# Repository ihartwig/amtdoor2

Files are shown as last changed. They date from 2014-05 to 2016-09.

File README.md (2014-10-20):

amtdoor2
========

This repository tracks files for AMT Door 2, an RFID based lock system in use at the [Ace Monster Toys](http://acemonstertoys.org/) hackspace in Oakland, CA. A complete description of the system these files are part of, [see the description on the AMT Wiki](http://wiki.acemonstertoys.org/Door#AMT_Door_2).

Included files:
* authCode - code to run on a raspberry pi or similar auth server
* housing - 2D drawings for assembly of the door tag reader
* hwTestCode - simplified panel mcu code to test clock settings
* panelMcuCode - firmware to run on the panel mcu that interprets RFID signals and accepts opening requests from the auth server
* physical - Eagle schematic/boards for the panel mcu

## Setting up on a 16u4:

to flash a new atmega16u4 for this code using an ISP (without the bootloader):

```
$ avrdude -p atmega16u4 -P usb -c avrispmkii -u -U lfuse:w:0xfc:m -U hfuse:w:0xd0:m -U efuse:w:0xc3:m
$ make MCU=atmega16u4
$ avrdude -p atmega16u4 -P usb -c avrispmkii -U flash:w:main.hex
```

to load the bootloader first using an ISP:

```
need to set fuses. we will copy from adafruit atmega32u4 dev board.
adafruit sets to: (E:C3, H:D0, L:FC) (avrdude-- has a typo)

Extended (0 is set):
7 1 Reserved
  1 Reserved
  0 Reserved
  0 Reserved
  0 HWBE          Hardware Boot Enable
  0 BODLEVEL2(1)  Brown-out Detector trigger level
  1 BODLEVEL1(1)  Brown-out Detector trigger level
0 1 BODLEVEL0(1)  Brown-out Detector trigger level

High (0 is set):
7 1 OCDEN         Enable OCD
  1 JTAGEN        Enable JTAG
  0 SPIEN         Enable Serial Program and Data Downloading
  1 WDTON         Watchdog Timer always on
  0 EESAVE        EEPROM memory is preserved through the Chip Erase
  0 BOOTSZ1       Select Boot Size (see Table 28-7 for details)
  0 BOOTSZ0       Select Boot Size (see Table 28-7 for details)
0 0 BOOTRST       Select Bootloader Address as Reset Vector

Low (0 is set):
7 1 CKDIV8        Divide clock by 8
  1 CKOUT         Clock output
  1 SUT1          Select start-up time
  1 SUT0          Select start-up time
  1 CKSEL3        Select Clock source
  1 CKSEL2        Select Clock source
  0 CKSEL1        Select Clock source
0 0 CKSEL0        Select Clock source
```

to compile CDC bootloader (from lufa-lib trunk):
for BOOTSZ1 = BOOTSZ0 = 0. see datasheet table 27-8.

```
$ make MCU=atmega16u4 BOOT_START=0x1800 F_CPU=16000000
$ mv BootloaderCDC.hex BootloaderCDC_16u4.hex
$ avrdude -p atmega16u4 -P usb -c avrispmkii -U flash:w:BootloaderCDC_16u4.hex
```

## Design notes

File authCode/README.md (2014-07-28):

amtdoor
=======

Code that manages authenticating to and opening our door.

`check.py` is a utility to look for syntax errors in a python script.

`door_force_open.py` will force the door to open in emergencies (can only run if door_test.py is NOT running, since it talks to the arduino).

`door_test.py` listens on the usb serial port (aka an arduino) for rfids coming in. Once it reads an rfid, it compares it against a local database of valid rfids, if it matches, it sends a command to the arduino to open the door

It also listens to the arduino for the door sensor, which reports when the door opens and closes.

All of the above are also sent via http to our server for logging.

`door_test.sh` is a wrapper around door_test.py that auto-restarts on error. This is started by the doortestd at system boot.

`doortestd` is a debian system daemon script that can be used to start and stop the door test but keep it running when there are no active users on the auth computer.

`getrfids.php` updates the local database of valid rfids from the server. Gets called from cron via update-amt-rfid script.

`setup.sh` provisions the system to act as an authentication server for our door by setting up the startup and cron jobs. This can be done manually like this:
```
$ sudo cp ./doortestd /etc/init.d/doortestd
$ sudo update-rc.d door_test defaults
$ sudo cp update-amt-rfid /etc/cron.hourly/
```
Will likely need to be call as su/sudo.

The system can be unprovisioned with:
```
$ sudo update-rc.d doortestd remove
$ sudo rm /etc/init.d/door_test
$ sudo rm /etc/cron.hourly/update-amt-rfid

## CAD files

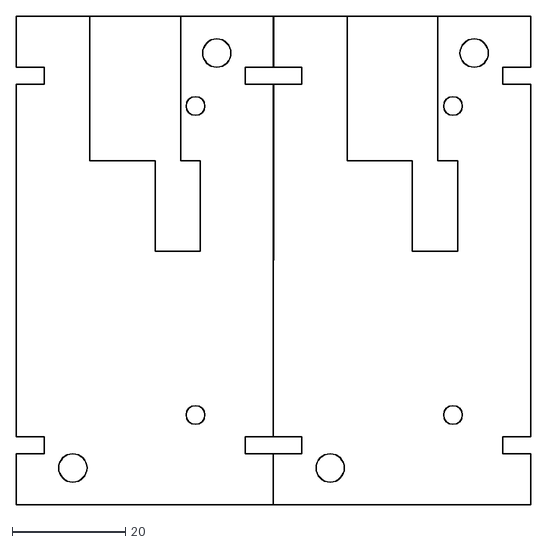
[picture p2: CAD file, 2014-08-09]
housing/amt door cut 1.dxf
90.8 x 86.2

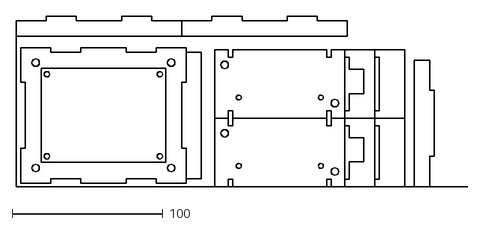
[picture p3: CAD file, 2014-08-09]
housing/amt door cut 0.dxf
300.0 x 113.0

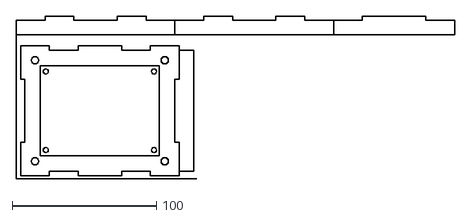
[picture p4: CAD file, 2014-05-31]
housing/amt door rfid housing.dxf
304.0 x 113.0

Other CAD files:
housing/panel_mcu_housing.dwg
housing/rfid_housing.dwg
housing/amt door cut 0.dwg
housing/amt door cut 1.dwg

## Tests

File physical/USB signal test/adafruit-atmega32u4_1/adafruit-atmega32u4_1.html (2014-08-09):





USB Test Report

Overall Results:0 of 3 Tests Failed

Test Configuration Details
Device Description
HSPacketParameter | DifferentialPP
HSSignalQuality | SMA
Use Pulse Generator | No
Test Method | USBET
Test Point | none
Test Session Details
Infiniium SW Version | 03.50.0010
Infiniium Model Number | DSO9254A
Infiniium Serial Number | MY52370102
Application SW Version | 3.81
Debug Mode Used | No
Probe (Channel 1) | Model: 10:1 1M Ohm Probe Serial: No Serial Num Atten: Calibrated (6 OCT 2012 05:12:08), Using Cal Atten (1.0070E+001) Skew: Not Calibrated, Using Default Skew
Probe (Channel 2) | Model: 10:1 1M Ohm Probe Serial: No Serial Num Atten: Not Calibrated, Using Default Atten (1.0000E+001) Skew: Not Calibrated, Using Default Skew
Probe (Channel 3) | Model: 10:1 1M Ohm Probe Serial: No Serial Num Atten: Calibrated (6 MAY 2014 16:39:34), Using Cal Atten (1.0152E+001) Skew: Not Calibrated, Using Default Skew
Last Test Date | 2014-07-28 11:12:02 UTC -07:00

## Summary of Results

Margin Thresholds
Warning | < 2 %
Critical | < 0 %

Pass | # Failed | # Trials | Test Name | Actual Value | Margin | Spec Range
 | 0 | 1 | Upstream Full Speed Signal Quality Test | Pass | 100.0 % | Pass/Fail
 | 0 | 1 | Upstream Full Speed Rise Time Test (information only) | Pass | 100.0 % | Pass/Fail
 | 0 | 1 | Upstream Full Speed Fall Time Test (information only) | Pass | 100.0 % | Pass/Fail

## Report Detail

 Upstream Full Speed Signal Quality Test Reference: USB 2.0 Specification, Section 7.1.11.,Section 7.1.2.1.

Test Summary: Pass Test Description: The full-speed data rate is nominally 12.000Mb/s. For both full-speed and low-speed signaling, the crossover voltage must be between 1.3V and 2.0V.
Test Limits:Pass/FailOverall Data Eye TestPass

Result Details:

Result Details
Port Under TestPort1Test Packet(See image)Eye Diagram(See image)LSFS Signal Eyeeye passesLSFS Signal Eye FailureN/ALSFS EOP Width TestPassLSFS EOP Width165.37 nsLSFS ReceiversN/ALSFS Signal Rate 11.9974 MHzLSFS Signal Rate TestPassLSFS Signal Rate FailureN/ALSFS Cross Over1.47 V to 1.53 VLSFS Cross Over Mean1.51 VLSFS Consecutive Jitter Range-908.312 ps to 696.659 psLSFS Consecutive RMS Jitter710.841 psLSFS Paired JK Jitter Range-148.354 ps to -32.990 psLSFS Paired JK RMS Jitter Range107.465 psLSFS Paired KJ Jitter Range-281.349 ps to 285.019 psLSFS Paired KJ RMS Jitter Range206.932 psLSFS JitterPassRisngEdge 163.02 FallingEdge 284.41

Trial 1

Trial 1: Test Packet

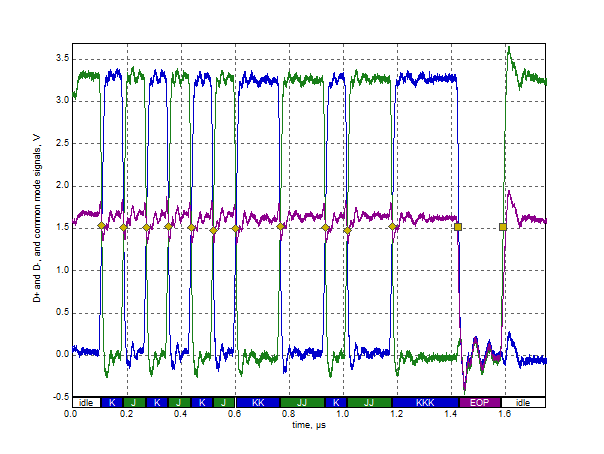
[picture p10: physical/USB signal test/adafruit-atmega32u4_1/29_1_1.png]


Trial 1: Eye Diagram

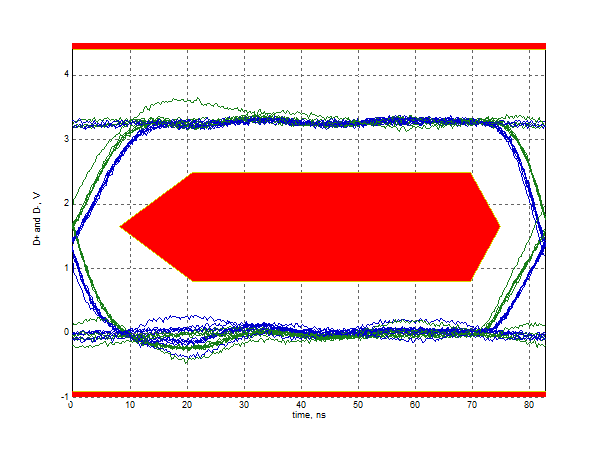
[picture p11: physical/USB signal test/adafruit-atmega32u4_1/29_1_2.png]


 Upstream Full Speed Rise Time Test (information only) Reference: USB 2.0 Specification, Section 7.1.11.,Section 7.1.2.2.

Test Summary: Pass Test Description: A USB Full Speed driver must have a single-ended rise and fall times between 4ns and 20ns. However, slew rate measurement will be made and expressed in terms of (V/us) to ensure waveform with slow corners will not result in a measured rise/fall time that is slower than the actual edge rate. The conversion from rise time to edge rate uses the specified rise time over 80% of the nominal peak to peak signal amplitude.
Test Limits:Pass/FailRise Time TestPass

Result Details:

Result Details
Test ConditionPassTest Range 4ns <= Actual Value <= 20ns Rise Time16.190 ns

 Upstream Full Speed Fall Time Test (information only) Reference: USB 2.0 Specification, Section 7.1.11.,Section 7.1.2.2.

Test Summary: Pass Test Description: A USB Full Speed driver must have a single-ended rise and fall times between 4ns and 20ns. However, slew rate measurement will be made and expressed in terms of (V/us) to ensure waveform with slow corners will not result in a measured rise/fall time that is slower than the actual edge rate. The conversion from rise time to edge rate uses the specified rise time over 80% of the nominal peak to peak signal amplitude.
Test Limits:Pass/FailFall Time TestPass

Result Details:

Result Details
Test ConditionPassTest Range 4ns <= Actual Value <= 20ns Fall Time9.280 ns

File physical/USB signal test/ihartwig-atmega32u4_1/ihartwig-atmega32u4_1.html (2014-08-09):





USB Test Report

Overall Results:0 of 3 Tests Failed

Test Configuration Details
Device Description
HSPacketParameter | DifferentialPP
HSSignalQuality | SMA
Use Pulse Generator | No
Test Method | USBET
Test Point | none
Test Session Details
Infiniium SW Version | 03.50.0010
Infiniium Model Number | DSO9254A
Infiniium Serial Number | MY52370102
Application SW Version | 3.81
Debug Mode Used | No
Probe (Channel 1) | Model: 10:1 1M Ohm Probe Serial: No Serial Num Atten: Calibrated (6 OCT 2012 05:12:08), Using Cal Atten (1.0070E+001) Skew: Not Calibrated, Using Default Skew
Probe (Channel 2) | Model: 10:1 1M Ohm Probe Serial: No Serial Num Atten: Not Calibrated, Using Default Atten (1.0000E+001) Skew: Not Calibrated, Using Default Skew
Probe (Channel 3) | Model: 10:1 1M Ohm Probe Serial: No Serial Num Atten: Calibrated (6 MAY 2014 16:39:34), Using Cal Atten (1.0152E+001) Skew: Not Calibrated, Using Default Skew
Last Test Date | 2014-07-28 11:35:18 UTC -07:00

## Summary of Results

Margin Thresholds
Warning | < 2 %
Critical | < 0 %

Pass | # Failed | # Trials | Test Name | Actual Value | Margin | Spec Range
 | 0 | 1 | Upstream Full Speed Signal Quality Test | Pass | 100.0 % | Pass/Fail
 | 0 | 1 | Upstream Full Speed Rise Time Test (information only) | Pass | 100.0 % | Pass/Fail
 | 0 | 1 | Upstream Full Speed Fall Time Test (information only) | Pass | 100.0 % | Pass/Fail

## Report Detail

 Upstream Full Speed Signal Quality Test Reference: USB 2.0 Specification, Section 7.1.11.,Section 7.1.2.1.

Test Summary: Pass Test Description: The full-speed data rate is nominally 12.000Mb/s. For both full-speed and low-speed signaling, the crossover voltage must be between 1.3V and 2.0V.
Test Limits:Pass/FailOverall Data Eye TestPass

Result Details:

Result Details
Port Under TestPort1Test Packet(See image)Eye Diagram(See image)LSFS Signal Eyeeye passesLSFS Signal Eye FailureN/ALSFS EOP Width TestPassLSFS EOP Width165.57 nsLSFS ReceiversN/ALSFS Signal Rate 11.9984 MHzLSFS Signal Rate TestPassLSFS Signal Rate FailureN/ALSFS Cross Over1.55 V to 1.62 VLSFS Cross Over Mean1.58 VLSFS Consecutive Jitter Range-848.672 ps to 686.408 psLSFS Consecutive RMS Jitter616.931 psLSFS Paired JK Jitter Range-136.159 ps to -132.254 psLSFS Paired JK RMS Jitter Range134.221 psLSFS Paired KJ Jitter Range-292.809 ps to 198.516 psLSFS Paired KJ RMS Jitter Range179.996 psLSFS JitterPassRisngEdge 178.33 FallingEdge 314.11

Trial 1

Trial 1: Test Packet

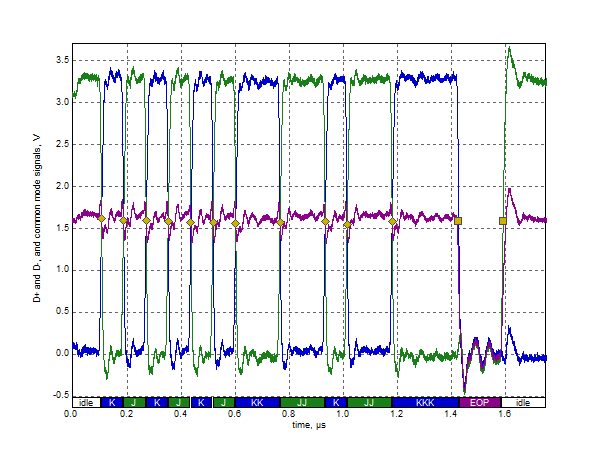
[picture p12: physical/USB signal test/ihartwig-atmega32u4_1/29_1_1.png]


Trial 1: Eye Diagram

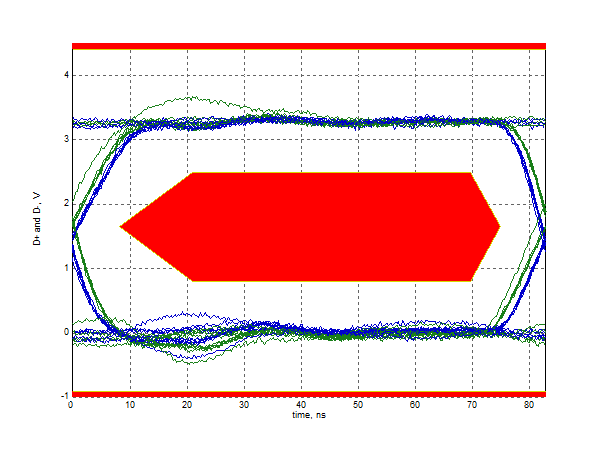
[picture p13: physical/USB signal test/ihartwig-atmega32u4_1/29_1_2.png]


 Upstream Full Speed Rise Time Test (information only) Reference: USB 2.0 Specification, Section 7.1.11.,Section 7.1.2.2.

Test Summary: Pass Test Description: A USB Full Speed driver must have a single-ended rise and fall times between 4ns and 20ns. However, slew rate measurement will be made and expressed in terms of (V/us) to ensure waveform with slow corners will not result in a measured rise/fall time that is slower than the actual edge rate. The conversion from rise time to edge rate uses the specified rise time over 80% of the nominal peak to peak signal amplitude.
Test Limits:Pass/FailRise Time TestPass

Result Details:

Result Details
Test ConditionPassTest Range 4ns <= Actual Value <= 20ns Rise Time14.800 ns

 Upstream Full Speed Fall Time Test (information only) Reference: USB 2.0 Specification, Section 7.1.11.,Section 7.1.2.2.

Test Summary: Pass Test Description: A USB Full Speed driver must have a single-ended rise and fall times between 4ns and 20ns. However, slew rate measurement will be made and expressed in terms of (V/us) to ensure waveform with slow corners will not result in a measured rise/fall time that is slower than the actual edge rate. The conversion from rise time to edge rate uses the specified rise time over 80% of the nominal peak to peak signal amplitude.
Test Limits:Pass/FailFall Time TestPass

Result Details:

Result Details
Test ConditionPassTest Range 4ns <= Actual Value <= 20ns Fall Time8.400 ns

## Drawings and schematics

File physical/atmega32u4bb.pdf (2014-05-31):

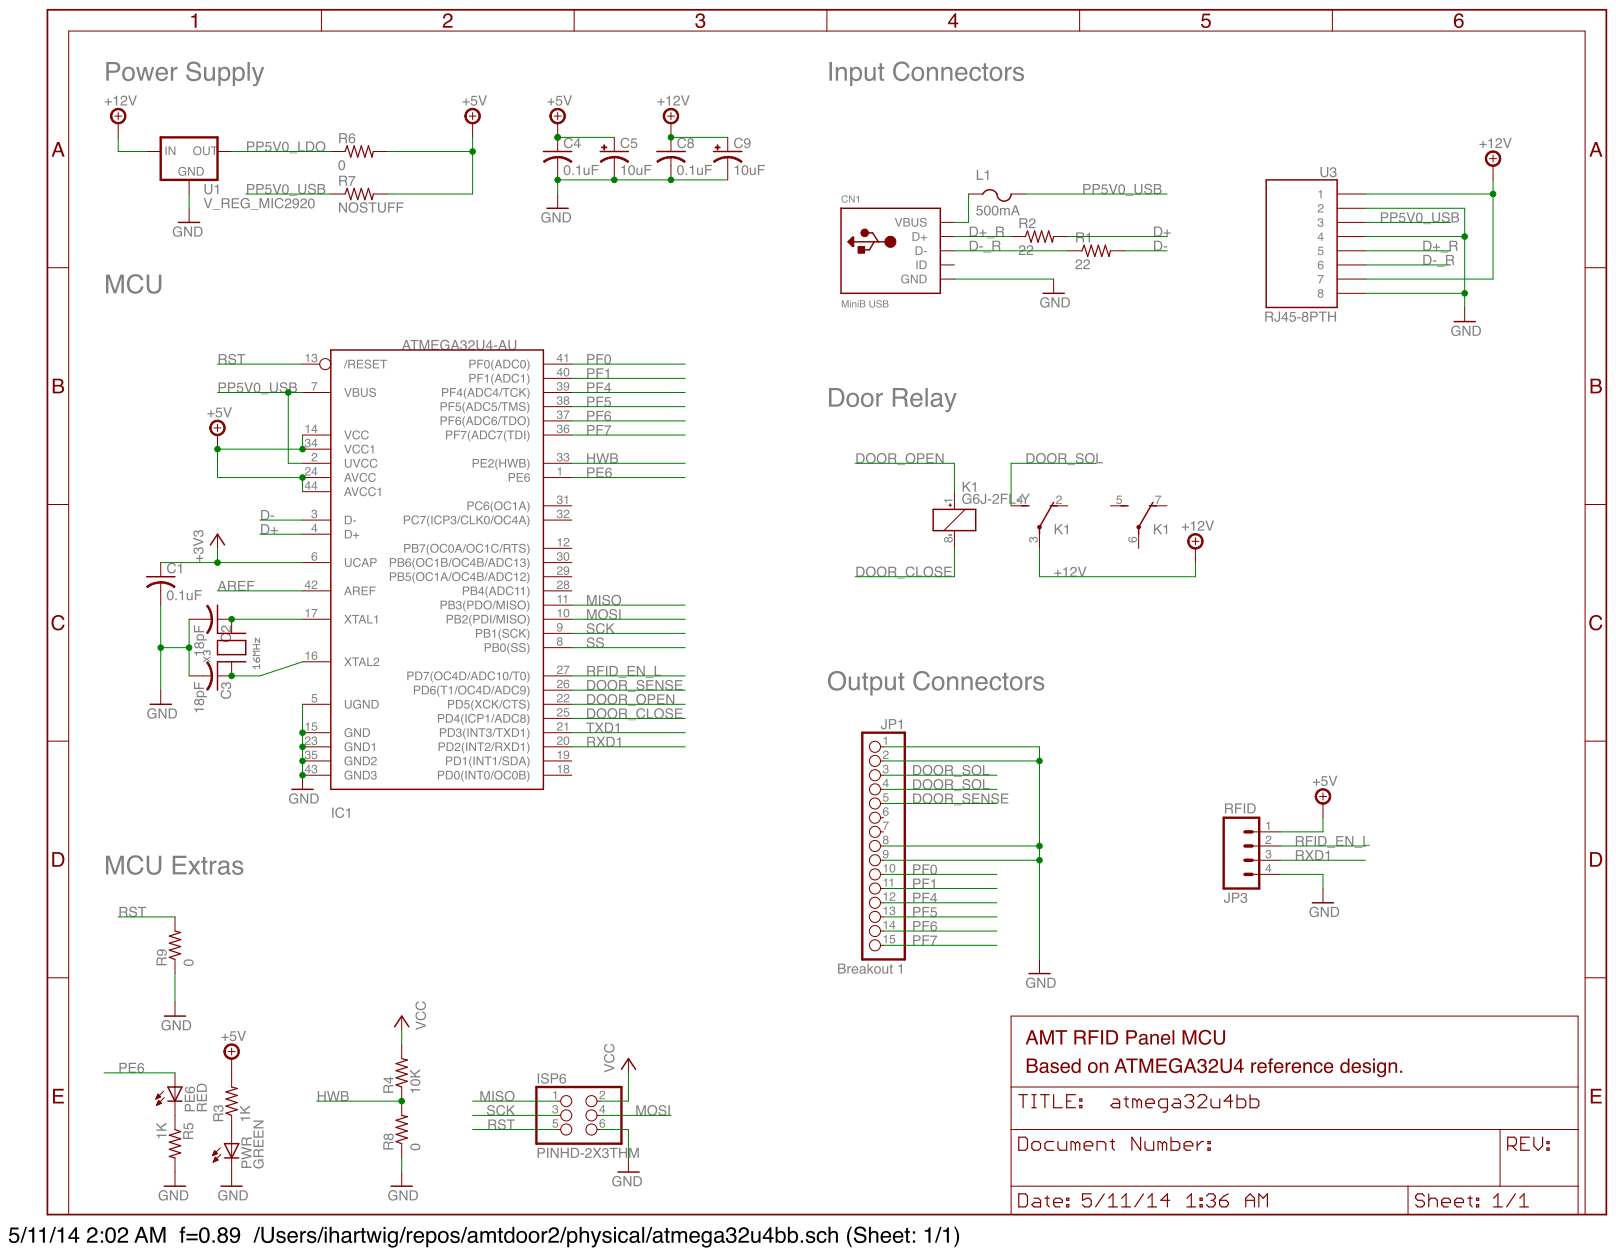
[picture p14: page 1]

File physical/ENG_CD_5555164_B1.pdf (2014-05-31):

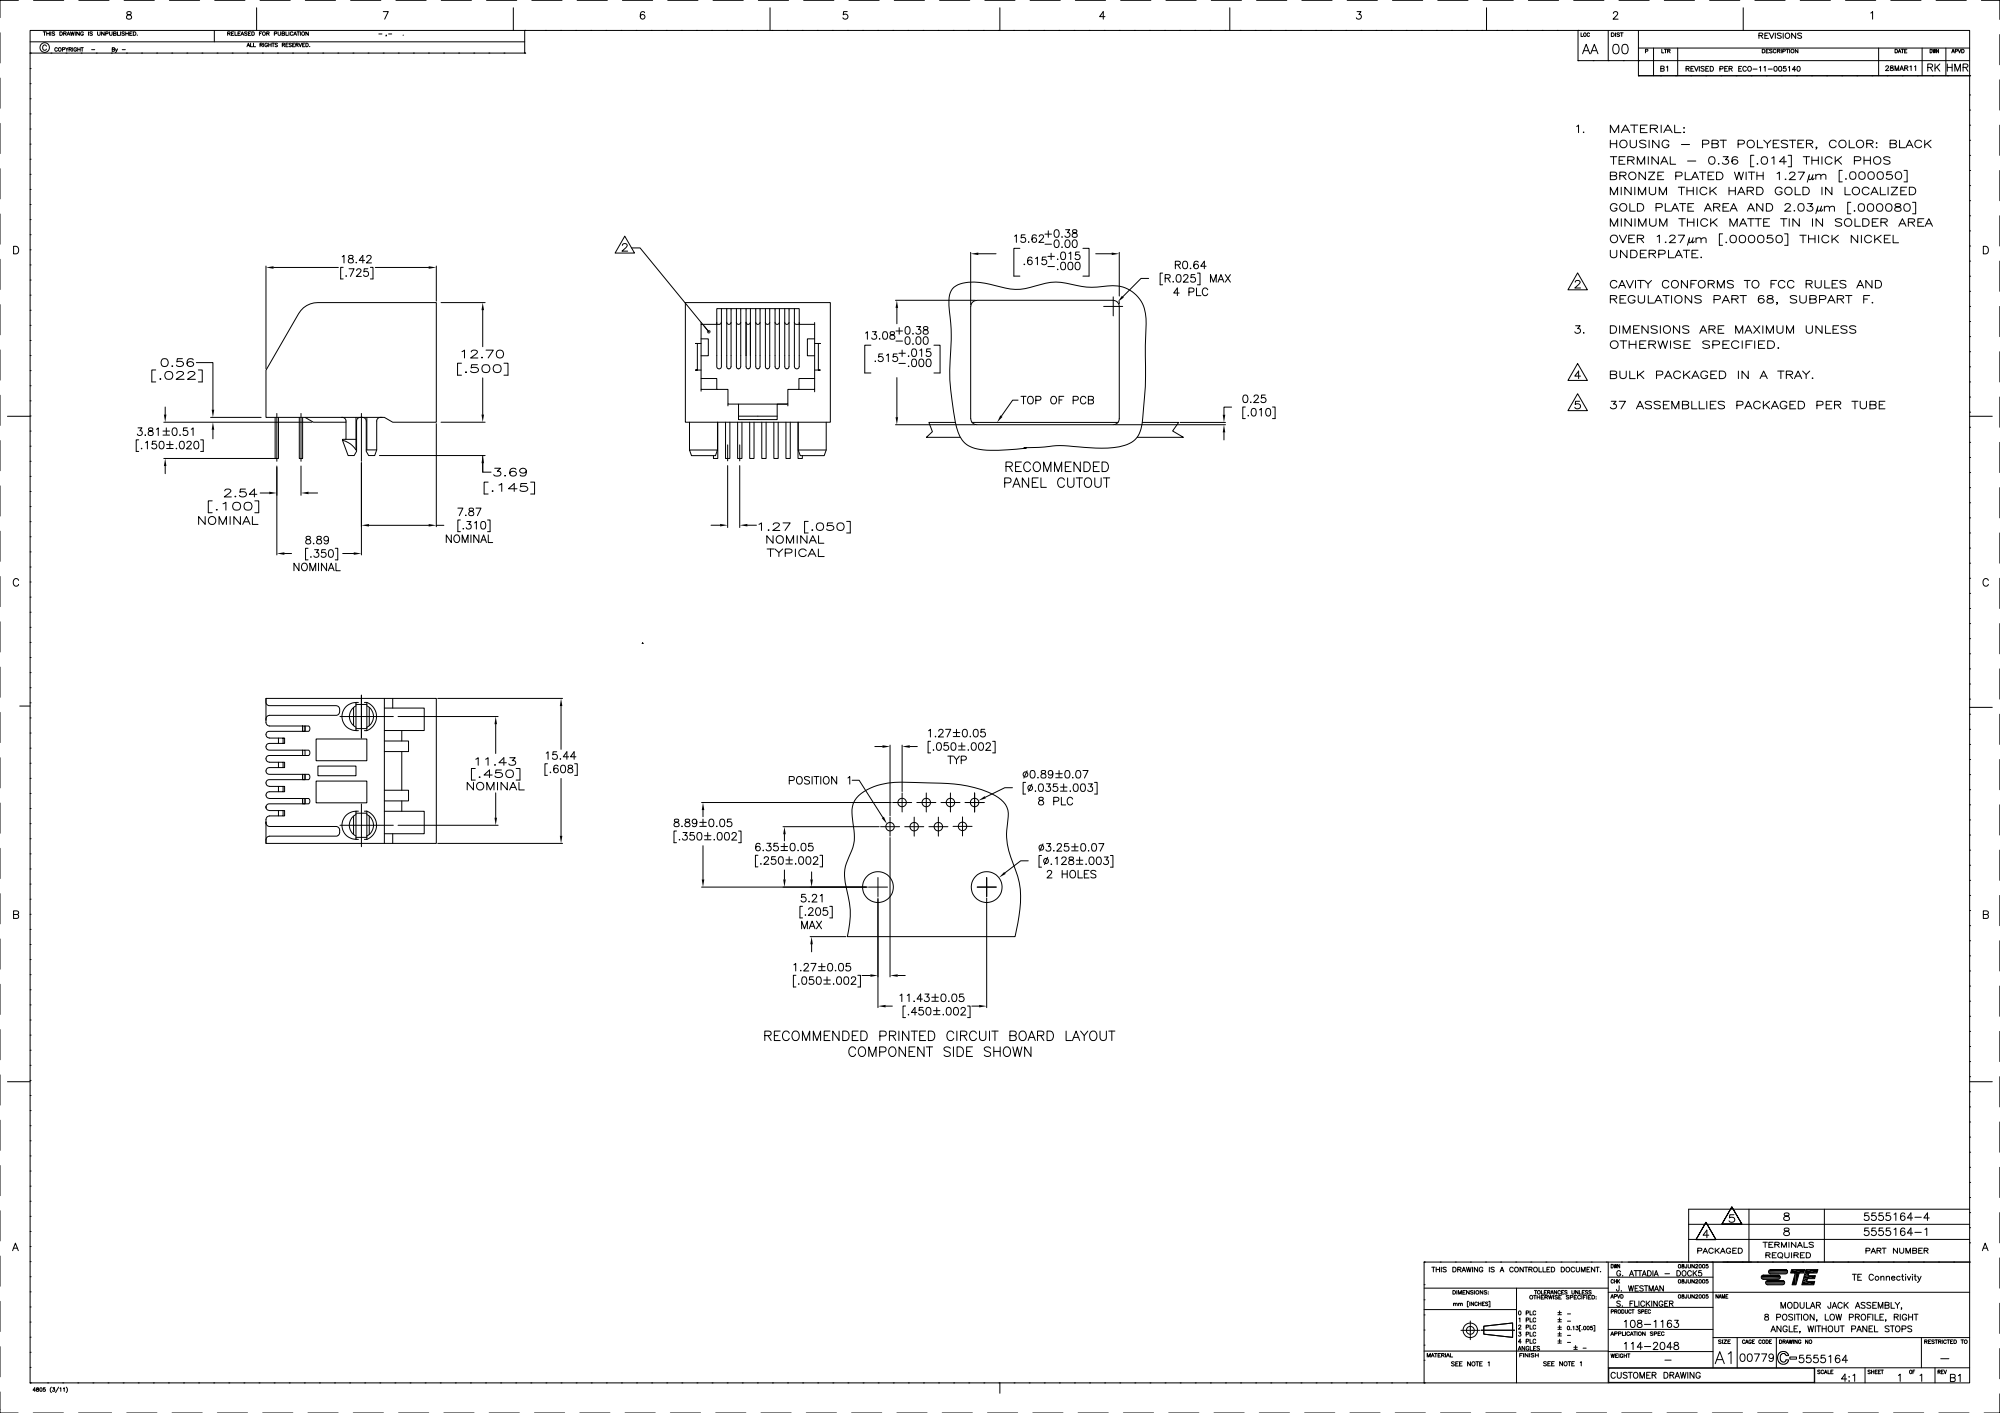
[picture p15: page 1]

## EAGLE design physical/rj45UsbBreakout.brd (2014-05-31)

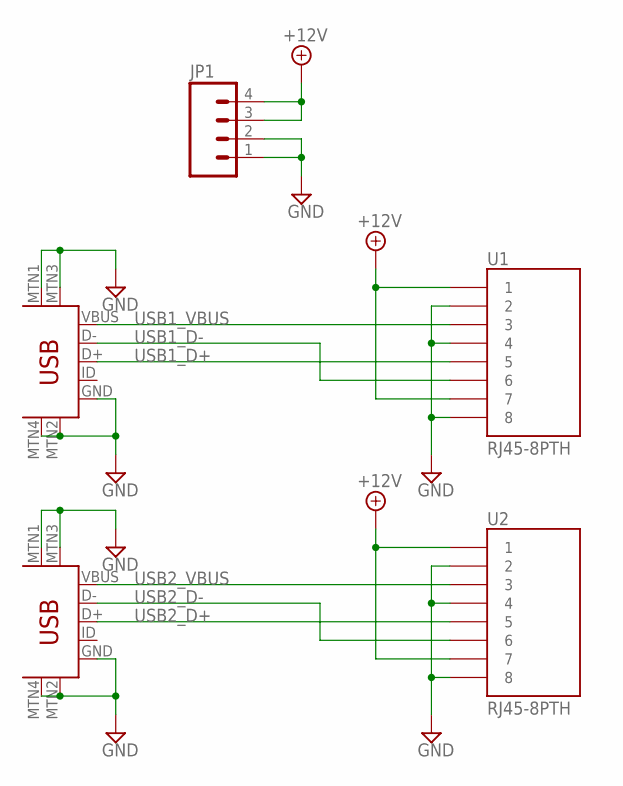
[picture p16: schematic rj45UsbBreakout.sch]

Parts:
JP1: M04LOCK; 1X04_LOCK
U1, U2: RJ45-8PTH; RJ45-8
U3, U4: USB-MINIB-5PIN; USB-MINIB

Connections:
+12V: JP1.3, JP1.4, U1.1, U1.7, U2.1, U2.7
GND: JP1.1, JP1.2, U1.2, U1.4, U1.8, U2.2, U2.4, U2.8, U3.GND, U3.MTN1 (MTN2), U3.MTN2 (MTN3), U3.MTN3 (MTN1), U3.MTN4, U4.GND, U4.MTN1 (MTN2), U4.MTN2 (MTN3), U4.MTN3 (MTN1), U4.MTN4
USB1_D+: U1.5, U3.D+
USB1_D-: U1.6, U3.D-
USB1_VBUS: U1.3, U3.VBUS
USB2_D+: U2.5, U4.D+
USB2_D-: U2.6, U4.D-
USB2_VBUS: U2.3, U4.VBUS

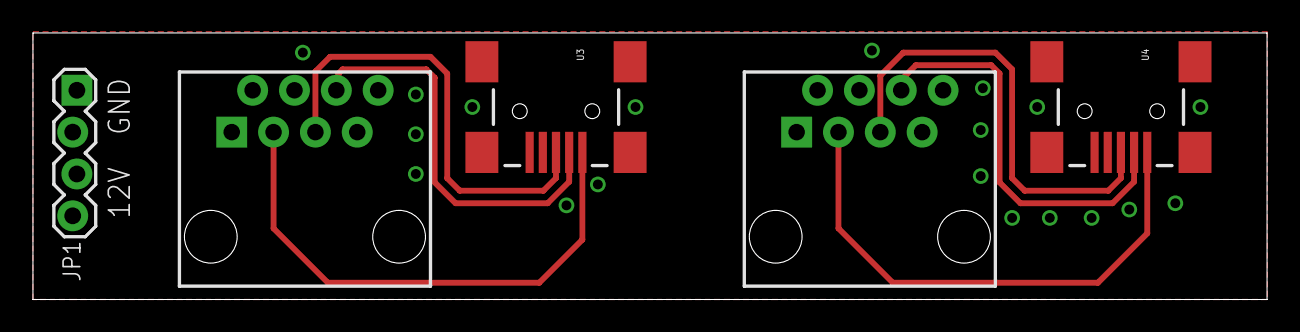
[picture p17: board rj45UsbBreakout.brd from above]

Board: 2 copper layers, 74.9 x 16.2 mm, 5 parts (0 on the bottom side), 8 nets.

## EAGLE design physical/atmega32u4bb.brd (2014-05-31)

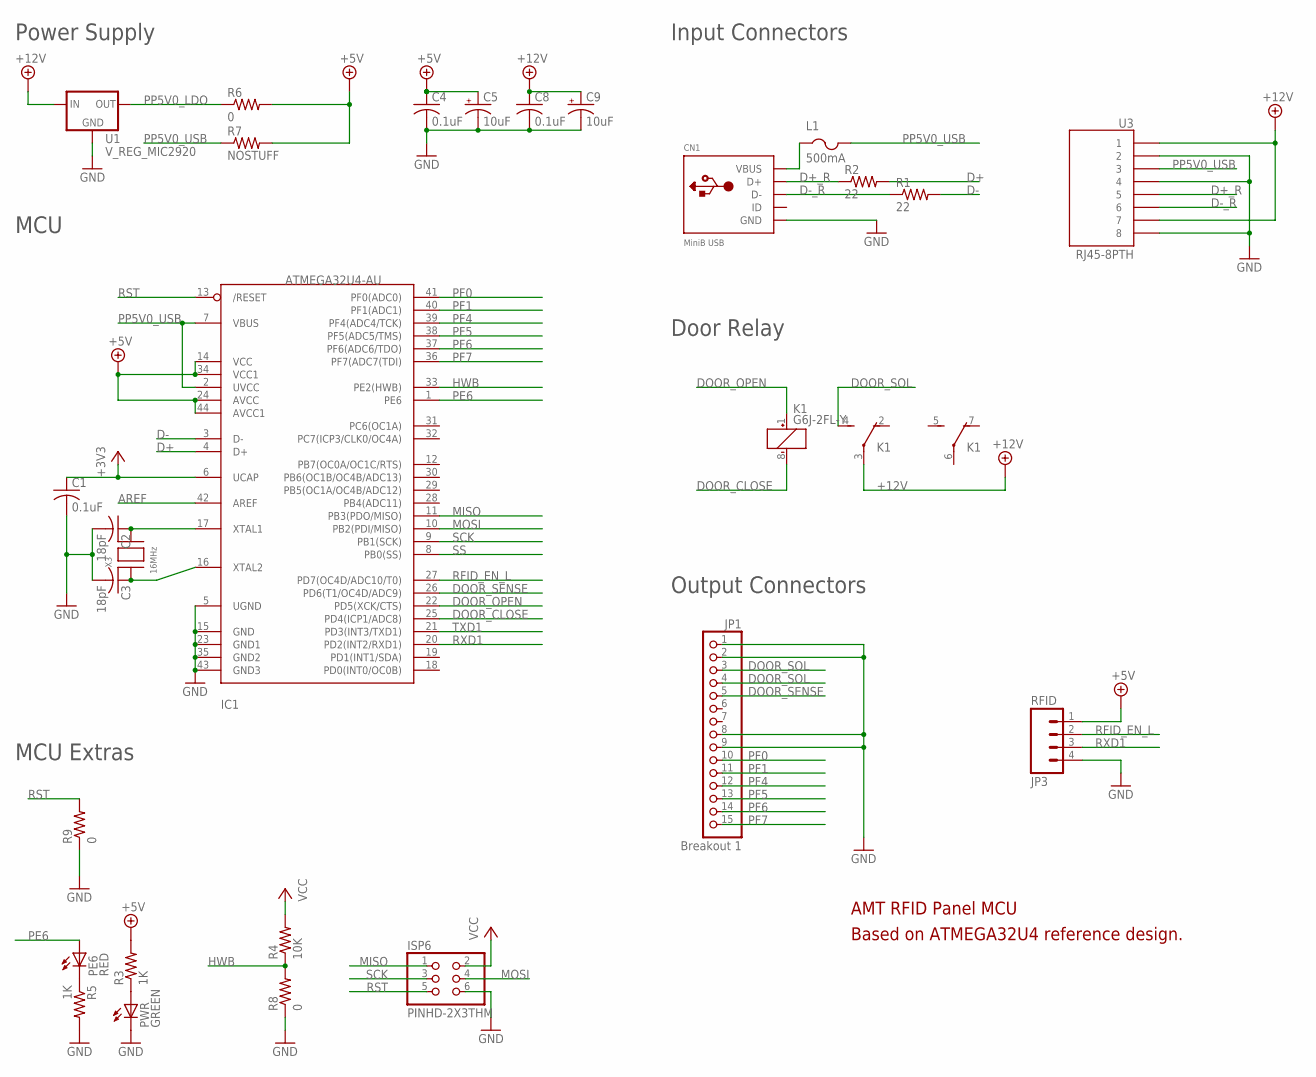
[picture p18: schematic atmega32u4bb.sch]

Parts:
C1, C4, C8: 0.1uF; C0805K
C2, C3: 18pF; C0805K
C5, C9: 10uF; A/3216-18R
CN1: MiniB USB; USB-MINIB
IC1: ATMEGA32U4-AU; TQFP44
ISP6: PINHD-2X3THM; ISP6
JP1: Breakout 1; 1X15-CB
JP3: RFID; 1X04_LOCK
K1: G6J-2FL-Y
L1: 500mA; R1206
PE6: RED; CHIPLED_0805
PWR: GREEN; CHIPLED_0805
R1, R2: 22; R0805
R3, R5: 1K; R0805
R4: 10K; R0805
R6, R8, R9: 0; R0805
R7: NOSTUFF; R0805
U1: V_REG_MIC2920; SOT223
U3: RJ45-8PTH; RJ45-8
X3: 16MHz; NX5032

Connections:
+3V3: C1.1, IC1.6 (UCAP)
+5V: C4.1, C5.+, IC1.14 (VCC), IC1.24 (AVCC), IC1.34 (VCC1), IC1.44 (AVCC1), JP3.1, R3.2, R6.2, R7.2
+12V: C8.1, C9.+, K1.3, U1.1 (IN), U3.1, U3.7
AREF: IC1.42 (AREF)
D+: IC1.4 (D+), R2.2
D+_R: CN1.D+, R2.1, U3.5
D-: IC1.3 (D-), R1.2
D-_R: CN1.D-, R1.1, U3.6
DOOR_CLOSE: IC1.25 (PD4(ICP1/ADC8)), K1.8 (-)
DOOR_OPEN: IC1.22 (PD5(XCK/CTS)), K1.1 (+)
DOOR_SENSE: IC1.26 (PD6(T1/OC4D/ADC9)), JP1.5
DOOR_SOL: JP1.3, JP1.4, K1.4 (S)
GND: C1.2, C2.2, C3.2, C4.2, C5.-, C8.2, C9.-, CN1.GND, IC1.5 (UGND), IC1.15 (GND), IC1.23 (GND1), IC1.35 (GND2), IC1.43 (GND3), ISP6.6, JP1.1, JP1.2, JP1.8, JP1.9, JP3.4, PWR.C, R5.2, R8.1, R9.1, U1.2 (GND), U1.4 (GND), U3.2, U3.4, U3.8
HWB: IC1.33 (PE2(HWB)), R4.1, R8.2
MISO: IC1.11 (PB3(PDO/MISO)), ISP6.1
MOSI: IC1.10 (PB2(PDI/MISO)), ISP6.4
unnamed: PWR.A, R3.1
unnamed: C2.1, IC1.17 (XTAL1), X3.P$2
unnamed: C3.1, IC1.16 (XTAL2), X3.P$1
unnamed: PE6.C, R5.1
PE6: IC1.1 (PE6), PE6.A
PF0: IC1.41 (PF0(ADC0)), JP1.10
PF1: IC1.40 (PF1(ADC1)), JP1.11
PF4: IC1.39 (PF4(ADC4/TCK)), JP1.12
PF5: IC1.38 (PF5(ADC5/TMS)), JP1.13
PF6: IC1.37 (PF6(ADC6/TDO)), JP1.14
PF7: IC1.36 (PF7(ADC7(TDI)), JP1.15
PP5V0_LDO: R6.1, U1.3 (OUT)
PP5V0_USB: IC1.2 (UVCC), IC1.7 (VBUS), L1.2, R7.1, U3.3
RFID_EN_L: IC1.27 (PD7(OC4D/ADC10/T0)), JP3.2
RST: IC1.13 (/RESET), ISP6.5, R9.2
RXD1: IC1.20 (PD2(INT2/RXD1)), JP3.3
SCK: IC1.9 (PB1(SCK)), ISP6.3
SS: IC1.8 (PB0(SS))
TXD1: IC1.21 (PD3(INT3/TXD1))
VBUS: CN1.VBUS, L1.1
VCC: ISP6.2, R4.2

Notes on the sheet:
AMT RFID Panel MCU
Based on ATMEGA32U4 reference design.
Power Supply
MCU
MCU Extras
Input Connectors
Door Relay
Output Connectors

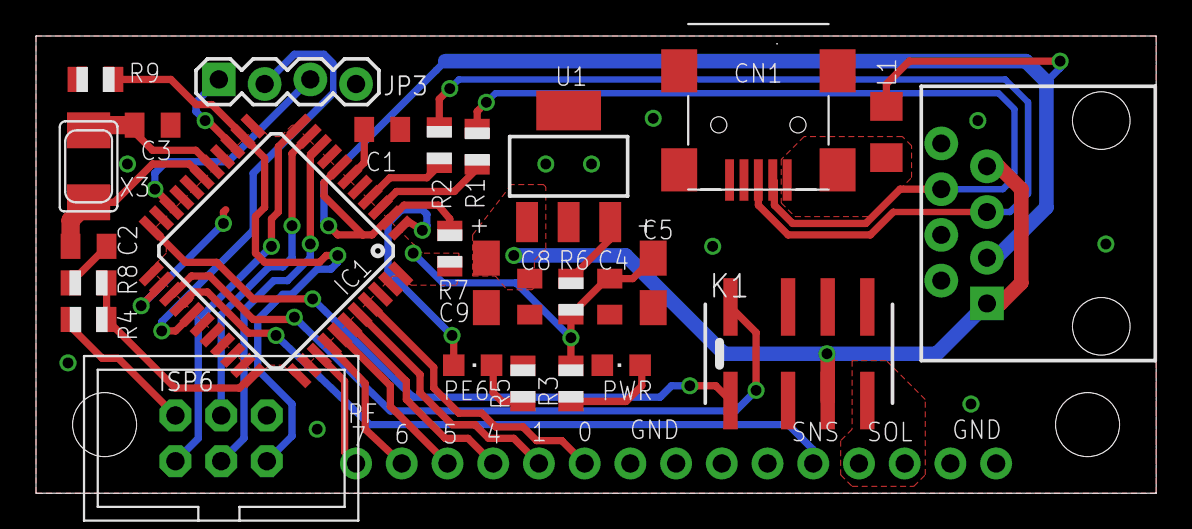
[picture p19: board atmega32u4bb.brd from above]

Board: 2 copper layers, 62.2 x 25.4 mm, 28 parts (0 on the bottom side), 34 nets.

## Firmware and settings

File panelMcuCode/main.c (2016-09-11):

#include "main.h"

/** LUFA CDC Class driver interface configuration and state information. This structure is
 *  passed to all CDC Class driver functions, so that multiple instances of the same class
 *  within a device can be differentiated from one another.
 */
USB_ClassInfo_CDC_Device_t VirtualSerial_CDC_Interface =
  {
    .Config =
      {
        .ControlInterfaceNumber   = INTERFACE_ID_CDC_CCI,
        .DataINEndpoint           =
          {
            .Address          = CDC_TX_EPADDR,
            .Size             = CDC_TXRX_EPSIZE,
            .Banks            = 1,
          },
        .DataOUTEndpoint =
          {
            .Address          = CDC_RX_EPADDR,
            .Size             = CDC_TXRX_EPSIZE,
            .Banks            = 1,
          },
        .NotificationEndpoint =
          {
            .Address          = CDC_NOTIFICATION_EPADDR,
            .Size             = CDC_NOTIFICATION_EPSIZE,
            .Banks            = 1,
          },
      },
  };


// standard file streams for the serial ios
static FILE USBSerialStream;
// static FILE HWSerialStream;

/* Global Data */
char_buffer_t command_buffer;
char_buffer_t tag_buffer;
device_state_t device_state;
doorsense_state_t doorsense_current;
doorsense_state_t doorsense_last;
volatile uint16_t system_timer; // 1ms resolution, loops at 2^16=65536ms
uint16_t last_system_timer;

int main (void) {
  initBuffer(&command_buffer);
  initBuffer(&tag_buffer);

  setupHardware();

  /* Create a regular character stream for the interface so that it can be used with the stdio.h functions */
  CDC_Device_CreateStream(&VirtualSerial_CDC_Interface, &USBSerialStream);
  // Serial_CreateStream(&HWSerialStream);

  GlobalInterruptEnable();

  // start state machine
  device_state = IDLE;
  // default to OPEN door; could also mean no sensor
  doorsense_last = OPEN;
  doorsense_current = OPEN;

  last_system_timer = 0;

  while (1) {
    // update door sense
    doorsense_last = doorsense_current;
    if(DOORSENSE_PIN & _BV(DOORSENSE_PINN)) {
      /**
       * Because input is pulled up + NO switch, we expect to see a high signal
       * when door is open or when no sensor is available.
       */
      doorsense_current = OPEN;
    } else {
      doorsense_current = CLOSED;
    }
    // LED reflects door state; open=on
    if(doorsense_current == OPEN) {
      LEDPORT |= _BV(LEDPINN);
    } else {
      LEDPORT &= ~_BV(LEDPINN);
    }

    // periodically send a close door pulse in idle
    if(device_state == IDLE && system_timer >= DOOR_CLOSE_TIME_MS) {
      doorClose();
    }

    // during timeout, lock door if we see OPEN->CLOSE doorsense
    if(device_state == UNLOCKED &&
       doorsense_last == OPEN &&
       doorsense_current == CLOSED) {
      doorClose();
    }

    // after open timeout, go back to idle state
    if(device_state == UNLOCKED && system_timer >= DOOR_OPEN_TIME_MS) {
      doorClose();
    }

    // process any incomming serial commands (single bytes)
    while(CDC_Device_BytesReceived(&VirtualSerial_CDC_Interface) > 0) {
      char new_command = CDC_Device_ReceiveByte(&VirtualSerial_CDC_Interface);
      switch(new_command) {
        case 'D':
          doorOpen();
          break;
        case 'd':
          doorClose();
          break;
        default:
          // ignore
          break;
      }
    }

    // check for new data from RFID card reader, return when ready
    while(Serial_IsCharReceived()) {
      if(readOrDumpBuffer(
           (char)Serial_ReceiveByte(),
           &tag_buffer)) {
        if(strlen(tag_buffer.buffer) == TAG_LENGTH && device_state == IDLE) {
          fputs("TAG|", &USBSerialStream);
          fputs(&tag_buffer, &USBSerialStream);
          fputs("\r\n", &USBSerialStream);
        } else {
          fputs("BADREAD\r\n", &USBSerialStream);
        }
      }
    }

    // call maintenance functions
    CDC_Device_USBTask(&VirtualSerial_CDC_Interface);
    USB_USBTask();
  }
  return 0;
}


void initBuffer(char_buffer_t *buffer) {
  buffer->buffer[0] = '\0';
  buffer->pos = 0;
  buffer->size = CHAR_BUFFER_SIZE;
}


/**
  Serial buffer control function.
  Attempt to read available characters into the buffer until either the buffer
  is full or a new line is reached. Omits newline, but adds null terminator.
  Skips empty lines with no data between newlines.
  Return: true if complete line available.
**/
bool readOrDumpBuffer(char new_char, char_buffer_t *buffer) {
  // fprintf(&USBSerialStream, "char:%c,pos:%d\r\n", new_char, buffer->pos);
  if(new_char == '\n' || new_char == '\r') {
    // ignore spurious newlines from /r/n or /n/r
    if(buffer->pos == 0) {
      return false;
    }
    else {
      // also drop the last character if it was part of /r/n or /n/r
      char last_char = buffer->buffer[buffer->pos-1];
      if(last_char == '\n' || last_char == '\r') {
        buffer->pos--;
      }
      // null terminate the buffer
      buffer->buffer[buffer->pos] = '\0';
      buffer->pos = 0;
      return true;
    }
  }
  else {
    if(buffer->pos + 1 >= buffer->size) {
      // if no space for null terminator, this buffer is full.
      buffer->pos = 0;
    }
    buffer->buffer[buffer->pos] = new_char;
    buffer->pos++;
    return false;
  }
}


void setupHardware(void) {
  /* Disable watchdog if enabled by bootloader/fuses */
  MCUSR &= ~(1 << WDRF);
  wdt_disable();

  /* Disable clock division */
  clock_prescale_set(clock_div_1);

  // port init
  LEDDDR |= _BV(LEDPINN); //set up pin 0 on port B, off by default
  LEDPORT &= ~_BV(LEDPINN);

  RFIDEN_DDR |= _BV(RFIDEN_PINN); // pull RFID enable pin low
  RFIDEN_PORT &= ~_BV(RFIDEN_PINN);

  DOORCLOSE_DDR |= _BV(DOORCLOSE_PINN); // pull relay close side low
  DOORCLOSE_PORT &= ~_BV(DOORCLOSE_PINN);

  DOOROPEN_DDR |= _BV(DOOROPEN_PINN); // pull relay open side low
  DOOROPEN_PORT &= ~_BV(DOOROPEN_PINN);

  DOORSENSE_DDR &= ~_BV(DOORSENSE_PINN); // input with pull up
  DOORSENSE_PORT |= _BV(DOORSENSE_PINN);

  DEBUG_DDR |= DEBUG_PINN_ALL; // pull all debug pins low
  DEBUG_PORT &= ~DEBUG_PINN_ALL;

  // system time setup
  initSystemTime();

  // start serial interfaces
  Serial_Init(RFID_UART_BAUD, false);
  USB_Init();
}


/**
Configure TIMER0 to raise an interrupt every 1ms and increment the system_time
variable.
**/
void initSystemTime() {
  // F_CPU = 16000000
  // F_Timer1 = 16000000/64 = 250000
  // 1ms @ 250000 hz = 250
  // configure TIMER0 to raise an interrupt every 1ms

  // set timer for no scaling Fovr = 16000000/256 = 62500Hz, CTC Mode
  TCCR0A |= _BV(WGM01);
  TCCR0B |= _BV(CS01) | _BV(CS00);
  TIMSK0 |= _BV(OCIE0A);
  OCR0A = 250;
}


void doorOpen() {
  // set device state/timer
  device_state = UNLOCKED;
  system_timer = 0;

  // disable keypad (also displays green)
  RFIDEN_PORT |= _BV(RFIDEN_PINN);

  // toggle relay open pin
  DOOROPEN_PORT |= _BV(DOOROPEN_PINN);
  _delay_ms(DOOR_RELAY_PULSE_MS);
  DOOROPEN_PORT &= ~_BV(DOOROPEN_PINN);
}


void doorClose() {
  // toggle relay close pin
  DOORCLOSE_PORT |= _BV(DOORCLOSE_PINN);
  _delay_ms(DOOR_RELAY_PULSE_MS);
  DOORCLOSE_PORT &= ~_BV(DOORCLOSE_PINN);

  // reenable keypad
  RFIDEN_PORT &= ~_BV(RFIDEN_PINN);

  // and assume device state/timer
  device_state = IDLE;
  system_timer = 0;
}


/** Event handler for the library USB Connection event. */
void EVENT_USB_Device_Connect(void)
{
  // LEDs_SetAllLEDs(LEDMASK_USB_ENUMERATING);
}


/** Event handler for the library USB Disconnection event. */
void EVENT_USB_Device_Disconnect(void)
{
  // LEDs_SetAllLEDs(LEDMASK_USB_NOTREADY);
}


/** Event handler for the library USB Configuration Changed event. */
void EVENT_USB_Device_ConfigurationChanged(void)
{
  bool ConfigSuccess = true;

  ConfigSuccess &= CDC_Device_ConfigureEndpoints(&VirtualSerial_CDC_Interface);

  // LEDs_SetAllLEDs(ConfigSuccess ? LEDMASK_USB_READY : LEDMASK_USB_ERROR);
}


/** Event handler for the library USB Control Request reception event. */
void EVENT_USB_Device_ControlRequest(void)
{
  CDC_Device_ProcessControlRequest(&VirtualSerial_CDC_Interface);
}


ISR(TIMER0_COMPA_vect) {
  // figure out when the next compare should happen by doing a sine table lookup
  system_timer++;
}

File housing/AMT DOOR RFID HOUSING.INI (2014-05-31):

[Technics_Laser_Data]
ModifyTechCFG=0
LayersNumber=2
ExportRows=1
ExportColumns=1
ExportRowSpace=0.00000
ExportColumnSpace=0.00000
ExportRowCW=0.00000
ExportColumnCW=0.00000
LogicOrgPositionX=898.14412
LogicOrgPositionY=423.69474
LogicOrgPositionZ=-9999999.00000
AtOnceExport=1
IsTwoLaserWorking=0
TableZeroPositionX=0.00000
TableZeroPositionY=0.00000
OutputTimes=1
DelayTime=0
FeedLength=0.00000
FeedSpeed=5.00000
FeedDelayTime=0
MinX=594.14412
MaxX=898.14412
MinY=423.69474
MaxY=536.69474
ChangeSerialNo=0
ArrayMinX=594.14412
ArrayMaxX=898.14412
ArrayMinY=423.69474
ArrayMaxY=536.69474
LayerColor_0=0
LayerColor_1=16711680
ClipBoxPower=90.00000
ClipBoxPower2=40.00000
ClipBoxOffsetLen=0.00000
ClipBoxSpeed=10.00000
AlignMachineZPos=0.00000
RouteLength=0.00000
RoutePointNumber=0
OffsetLaserPower=0.00000
OffsetWorkSpeedPer=1.00000
ZHeightForLaserFocus=0.00000
OneWorkNeedTimes=0
TotalWorkTimes=0
[CoordSystem_0]
LogicOrgPosition1=898.14412
LogicOrgPosition2=423.69474
LogicOrgPosition3=-9999999.00000
SPLITBLOCK_NUMBER=0
[CreateTechnicsCodeMgr]
PrjHasModifyCFG=1
[TechnicsLayers_0]
TechnicsMode=TECHNICS_LASERCUT
LaserCutConnerPower=60.00000
LaserCutWorkPower=60.00000
LaserCutConnerPower2=30.00000
LaserCutWorkPower2=50.00000
LaserCutFrequency=20000
LaserCutOptimizePathType=1
LaserCutInnerToOuter=1
LaserCutInnerToOuter2=0
LaserCutDownToUpper=0
LaserCutBlockHeight=150.00000
LaserCutAutoSetPathDir=0
LaserCutCicleMinSegNumber=36
LaserCutDisperseLength=0.05000
LaserCutCloseGapLength=0.09000
LaserCutOverlapLength=0.00000
LaserCutAdjustForClose=0
LaserCutQXEnterLength=0.00000
LaserCutDelayMoveTime=0.00000
LaserCutOpenGZDelayTime=0.00000
LaserCutOpenLaserDelayTime=0.00000
LaserCutCloseLaserDelayTime=0.00000
LaserCutDelayTimeAfterCloseLaser=0.00000
LaserCutOneAxisBackLashLength=0.00000
LaserCutTwoAxisBackLashLength=0.00000
LaserCutBackLashAddSpaceLength=8.00000
LaserCutBlowGasType=1
LaserCutAheadBlowGasTimes=0.00000
LaserCutNoCloseGasTimes=0.00000
LaserCutSpeed=15.00000
LaserCutGWAcc=120.00000
LaserCutGWTime=0.01000
LaserCutTrackSize=100
LaserCutLineLength=0.00000
SpaceCutLineLength=0.00000
bSpaceLineFirst=0
LaserCutAdjustMove=0
LaserCutAdjustMoveDelay=0.00000
LaserCutUpLen=0.00000
LaserCutCircleSpeedNum=6
LaserCutCircleSpeed0_MinR=0.00000
LaserCutCircleSpeed0_MaxR=0.55000
LaserCutCircleSpeed0_Speed=15.00000
LaserCutCircleSpeed1_MinR=0.55000
LaserCutCircleSpeed1_MaxR=1.05000
LaserCutCircleSpeed1_Speed=20.00000
LaserCutCircleSpeed2_MinR=1.05000
LaserCutCircleSpeed2_MaxR=1.55000
LaserCutCircleSpeed2_Speed=25.00000
LaserCutCircleSpeed3_MinR=1.55000
LaserCutCircleSpeed3_MaxR=2.05000
LaserCutCircleSpeed3_Speed=30.00000
LaserCutCircleSpeed4_MinR=2.05000
LaserCutCircleSpeed4_MaxR=3.05000
LaserCutCircleSpeed4_Speed=35.00000
LaserCutCircleSpeed5_MinR=3.05000
LaserCutCircleSpeed5_MaxR=4.05000
LaserCutCircleSpeed5_Speed=40.00000
GROUP_ROWS_0=1
GROUP_COLUMNS_0=1
GROUP_ROWSPACE_0=0.00000
GROUP_COLUMNSPACE_0=0.00000
GROUP_ROWCWSPACE_0=0.00000
GROUP_COLUMNCWSPACE_0=0.00000
GROUP_MINX_0=594.14412
GROUP_MAXX_0=898.14412
GROUP_MINY_0=423.69474
GROUP_MAXY_0=536.69474
[TechnicsLayers_16711680]
TechnicsMode=TECHNICS_LASERENGRAVE
LaserCutConnerPower=60.00000
LaserCutWorkPower=60.00000
LaserCutConnerPower2=30.00000
LaserCutWorkPower2=50.00000
LaserCutFrequency=20000
LaserCutOptimizePathType=1
LaserCutInnerToOuter=1
LaserCutInnerToOuter2=0
LaserCutDownToUpper=0
LaserCutBlockHeight=150.00000
LaserCutAutoSetPathDir=0
LaserCutCicleMinSegNumber=36
LaserCutDisperseLength=0.05000
LaserCutCloseGapLength=0.09000
LaserCutOverlapLength=0.00000
LaserCutAdjustForClose=0
LaserCutQXEnterLength=0.00000
LaserCutDelayMoveTime=0.00000
LaserCutOpenGZDelayTime=0.00000
LaserCutOpenLaserDelayTime=0.00000
LaserCutCloseLaserDelayTime=0.00000
LaserCutDelayTimeAfterCloseLaser=0.00000
LaserCutOneAxisBackLashLength=0.00000
LaserCutTwoAxisBackLashLength=0.00000
LaserCutBackLashAddSpaceLength=8.00000
LaserCutBlowGasType=1
LaserCutAheadBlowGasTimes=0.00000
LaserCutNoCloseGasTimes=0.00000
LaserCutSpeed=15.00000
LaserCutGWAcc=120.00000
LaserCutGWTime=0.01000
LaserCutTrackSize=100
LaserCutLineLength=0.00000
SpaceCutLineLength=0.00000
bSpaceLineFirst=0
LaserCutAdjustMove=0
LaserCutAdjustMoveDelay=0.00000
LaserCutUpLen=0.00000
LaserCutCircleSpeedNum=6
LaserCutCircleSpeed0_MinR=0.00000
LaserCutCircleSpeed0_MaxR=0.55000
LaserCutCircleSpeed0_Speed=15.00000
LaserCutCircleSpeed1_MinR=0.55000
LaserCutCircleSpeed1_MaxR=1.05000
LaserCutCircleSpeed1_Speed=20.00000
LaserCutCircleSpeed2_MinR=1.05000
LaserCutCircleSpeed2_MaxR=1.55000
LaserCutCircleSpeed2_Speed=25.00000
LaserCutCircleSpeed3_MinR=1.55000
LaserCutCircleSpeed3_MaxR=2.05000
LaserCutCircleSpeed3_Speed=30.00000
LaserCutCircleSpeed4_MinR=2.05000
LaserCutCircleSpeed4_MaxR=3.05000
LaserCutCircleSpeed4_Speed=35.00000
LaserCutCircleSpeed5_MinR=3.05000
LaserCutCircleSpeed5_MaxR=4.05000
LaserCutCircleSpeed5_Speed=40.00000
LaserEngravePower=15.00000
LaserEngravePower2=60.00000
LaserEngraveFrequency=20000
LaserEngraveSpeed=300.00000
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

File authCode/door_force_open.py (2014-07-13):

#!/usr/bin/env python

import urllib 
import serial
import os
import sys

from datetime import datetime
from time import sleep


def connect(device, rate):
	return serial.Serial(device, rate)


ARDUINO_RATE = 9600

try:
    arduino = connect("/dev/ttyACM0", ARDUINO_RATE)
    print "Opened on ACM0"
except serial.serialutil.SerialException:
    try:
        arduino = connect("/dev/ttyACM1", ARDUINO_RATE)
        print "Opened on ACM1"
    except serial.serialutil.SerialException:
        print "Couldn't open USB? Try 'ls /dev/ttyACM*' and then modify the code"
	sys.exit()

while True:
	print "Sending open command..."
	arduino.write('D')
	sleep(30)
#	else:
#		arduino.write('G')
#		arduino.close()
#		arduino = connect(ARDUINO_PORT, ARDUINO_RATE)

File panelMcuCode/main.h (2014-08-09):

#ifndef _MAIN_H_
#define _MAIN_H_


/* Includes: */
#include <avr/io.h>
#include <avr/wdt.h>
#include <avr/power.h>
#include <avr/interrupt.h>
#include <string.h>
#include <stdio.h>

#include "descriptors.h"

#include <LUFA/Drivers/Peripheral/Serial.h>
#include <LUFA/Drivers/USB/USB.h>
#include <LUFA/Platform/Platform.h>


/* HW Setup */

//
#define LEDDDR  DDRE
#define LEDPORT PORTE
#define LEDPIN  PINE
#define LEDPINN 6

// RFID Enable & Red/Green LED
#define RFIDEN_DDR  DDRD
#define RFIDEN_PORT PORTD
#define RFIDEN_PIN  PIND
#define RFIDEN_PINN 7

// Door Control Relay
#define DOOROPEN_DDR  DDRD
#define DOOROPEN_PORT PORTD
#define DOOROPEN_PIN  PIND
#define DOOROPEN_PINN 5

#define DOORCLOSE_DDR  DDRD
#define DOORCLOSE_PORT PORTD
#define DOORCLOSE_PIN  PIND
#define DOORCLOSE_PINN 4

// Door Open/Close Sense
// NOTE: JP1.6 and JP1.7 need to be tied to GND
#define DOORSENSE_DDR  DDRD
#define DOORSENSE_PORT PORTD
#define DOORSENSE_PIN  PIND
#define DOORSENSE_PINN 6

// Extra/debug pins
#define DEBUG_DDR      DDRF
#define DEBUG_PORT     PORTF
#define DEBUG_PIN      PINF
#define DEBUG_PINN_ALL 0xF3

#define CHAR_BUFFER_SIZE 128
#define TAG_LENGTH 10
#define RFID_UART_BAUD 2400

// Periodic close re-assert
#define DOOR_CLOSE_TIME_MS 10000
// Timeout when door is read as open
#define DOOR_OPEN_TIME_MS 8000
// Pulse fed to door control relay
#define DOOR_RELAY_PULSE_MS 50


/* Data Structures */
typedef struct char_buffer_t {
  char buffer[CHAR_BUFFER_SIZE];
  size_t pos;
  size_t size;
} char_buffer_t;

/**
 * IDLE (non blocking) -> Wait for new serial data ->
 * VERIFYING (non blocking) -> Should get a door command? (not really used) ->
 * UNLOCKED (blocking) -> Open relay, disable reader, set 10s timer.
 * When in non-UNLOCKED states, pulse close signal every 10s.
 **/
typedef enum device_state_t {
  IDLE,
  VERIFYING,
  UNLOCKED
} device_state_t;

/**
 * Track the door sense state.
 **/
typedef enum doorsense_state_t {
  OPEN,
  CLOSED
} doorsense_state_t;

/* Function Prototypes: */
bool readOrDumpBuffer(char new_char, char_buffer_t *buffer);
void setupHardware(void);
void initSystemTime(void);
void doorOpen(void);
void doorClose(void);
// void RFIDEnable(void);
// void RFIDDisable(void);

void EVENT_USB_Device_Connect(void);
void EVENT_USB_Device_Disconnect(void);
void EVENT_USB_Device_ConfigurationChanged(void);
void EVENT_USB_Device_ControlRequest(void);


#endif

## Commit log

2014-05-31 add rev 1 of controller and usb-rj45 breakout boards
    [atmega32u4bb.brd, atmega32u4bb.sch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]
2014-05-31 add external panel laser files
    [amt door rfid housing.dwg, amt door rfid housing.dxf]
2014-06-08 implemented 1ms system timer
2014-07-13 add hw test and auth (raspberry pi/shevaplug) code
2014-07-27 fix relay pin assignments. remove debug statements.
    [main.c, main.h]
2014-07-27 tweak relay pulse length
2014-07-27 disable second led by default to conserve power/reduce thermal load on ldo
2014-08-09 add new laser files for panel mcu (since this can't be outside)
    [amt door cut 0.dwg, amt door cut 0.dxf, amt door cut 1.dwg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]
2016-09-11 fix panelMcuCode not reading the latest rfid tag
    The Parallax RFID reader sends tags of value XXXXXXXX in the format "\nXXXXXXXX\r". Since we handled \r\n by ignoring \r and reading \n we always left the most recent tag in the buffer. Now we read the buffer for either \r or \n.
    [main.c]

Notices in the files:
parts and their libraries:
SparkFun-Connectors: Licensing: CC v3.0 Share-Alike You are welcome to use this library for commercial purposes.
